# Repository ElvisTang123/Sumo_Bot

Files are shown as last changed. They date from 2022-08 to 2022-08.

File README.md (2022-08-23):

<p align="center">
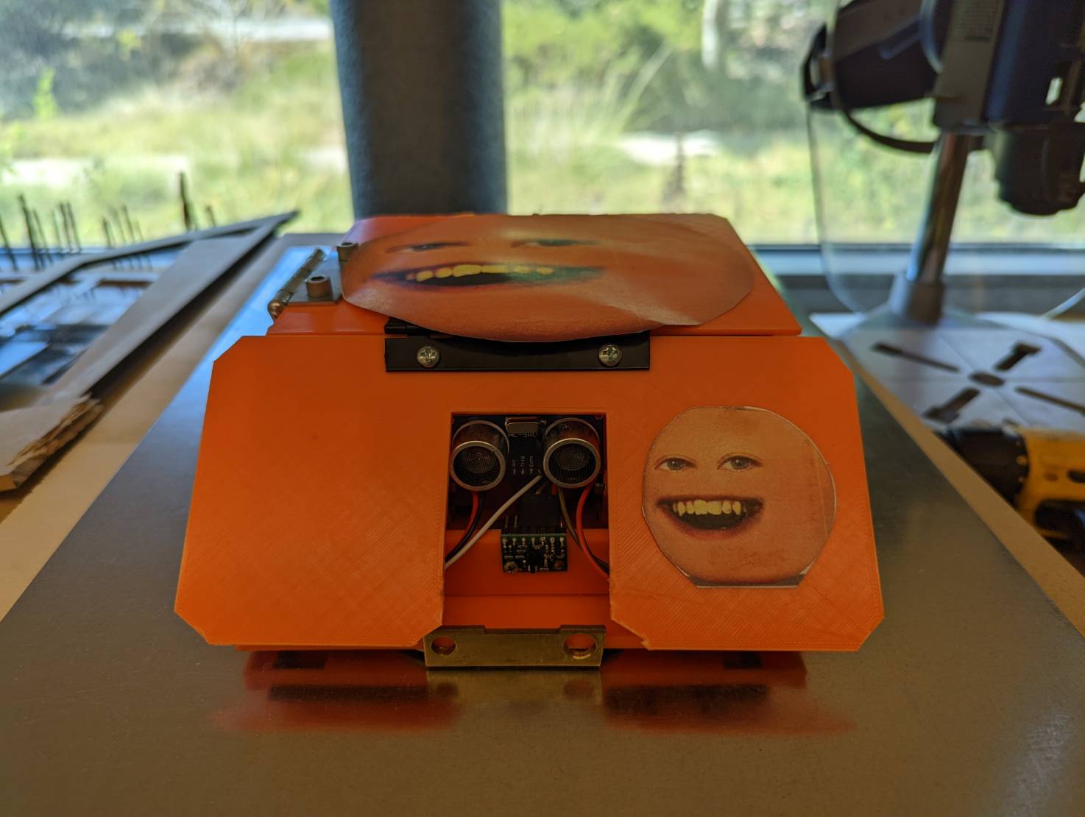
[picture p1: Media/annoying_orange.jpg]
  
</p>

<div align="center">
  <h1>Sumo_Bot - Annoying Orange</h1>
</div>

# Project Introduction
Sumo Bot is a sport that two robots try to push each other out of the circle arena. In order to push other robot out and keep themselves in the arena, normally there are a few line detect sensors at the bottom of the robot to sense the edge of the arena and couples of distance sensors on the robot to measure their opponents' location.<br />
In this project, we are going to build a sumo bot from scratch. This includes the PCB design, car shell CAD design, and firmware development for motors, sensors and other electronic components.<br />

# Table of Contents
* [Accomplishments](#accomplishments)
* [Bill of Materials](#bill-of-materials)
* [Mechanical Design](#mechanical-design)
* [PCB Design](#pcb-design)
* [High Level Wiring Diagram](#high-level-wiring-diagram)
* [Demonstration](#demonstration)

# Accomplishments
* Built a robot with 4 DC motors, 2 light reflect sensors, a laser ToF sensor, an IMU sensor, and a 3D printed shell
* Designed a PCB board containing voltage regulator, fuse, MCU chip, motor drivers, and voltage monitoring circuit
* Developed mannul mode (control the robot with remote control) and auto mode (robot's action is based on sensors' data feedback) for sumo bot control
* Designed the auto mode algorithms according to the sensors' data feedback in C programming

# Bill of Materials

| Components | Part # | Quantity |
| :---:  | :---: |:---: |
| DC Motor | 25D HP 12V Metal Gearmotors| 4 |
| Motor Driver |DRV8800PWP|4|
| ToF Laser Sensor | VL53L0X |1|
| Ultrasonic Distance Sensor | HC-SR04 |1|
| Infrared Reflective Sensor | TCRT5000 |2|
| Inertial measurement unit | MPU6050 |1|
| Remote Control Receiver | DUMBORC X6F |1|
| Wheels | JS4311 Aluminum |3|
| PCB Board | --- |1|

# Mechanical Design
The full CAD model for the assembly of the sumo bot can be found in the [CAD folder](https://github.com/ElvisTang123/Sumo_Bot/tree/main/CAD%20Files)
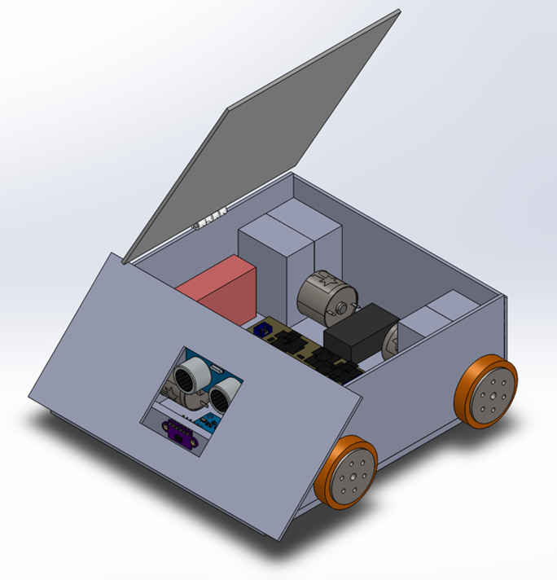
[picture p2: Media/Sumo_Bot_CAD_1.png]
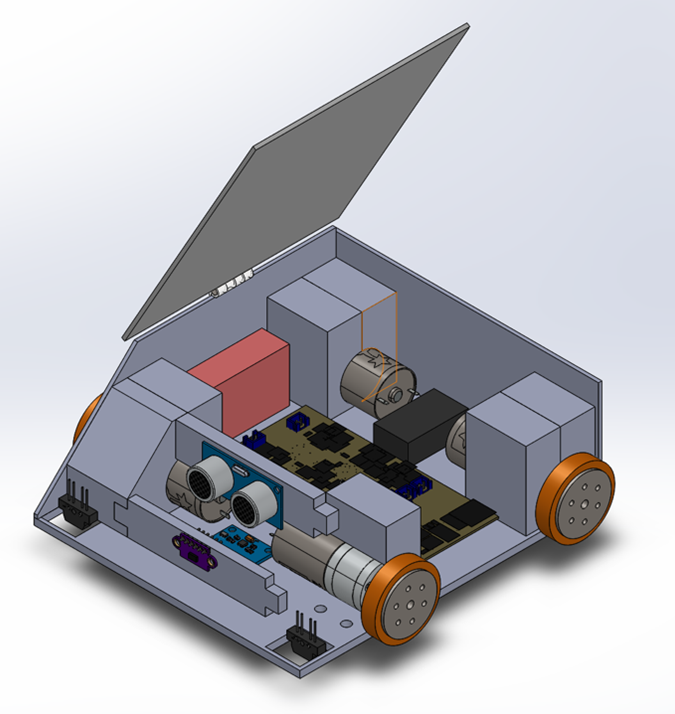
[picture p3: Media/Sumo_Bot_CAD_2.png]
|  | |
| --- | --- |

# PCB Design
The schematic and layout of the PCB board can be found in the [PCB Design](https://github.com/ElvisTang123/Sumo_Bot/tree/main/PCB%20Design)
<p align="center">
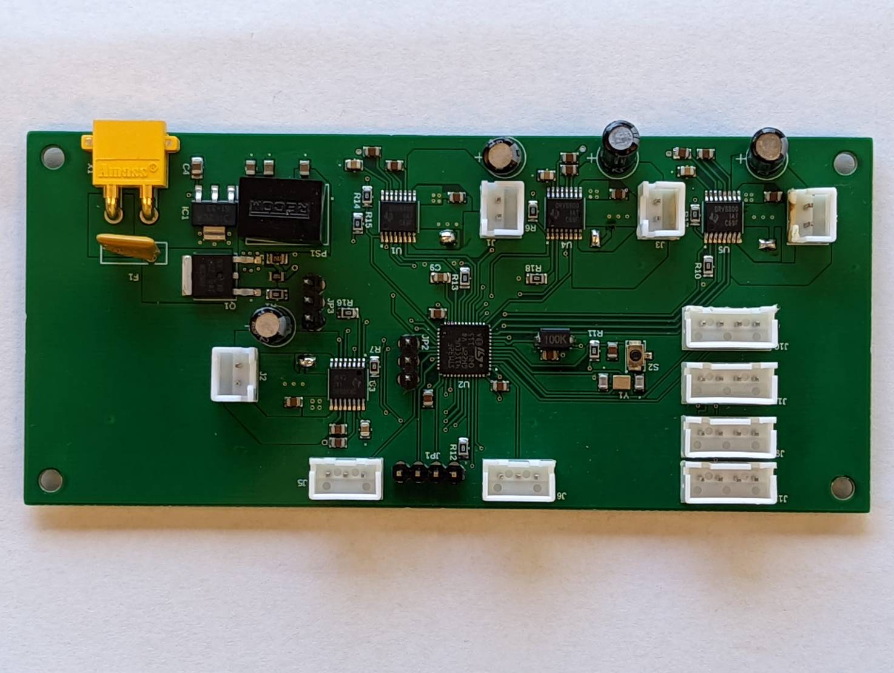
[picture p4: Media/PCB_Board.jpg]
  
</p>

# High Level Wiring Diagram
<p align="center">
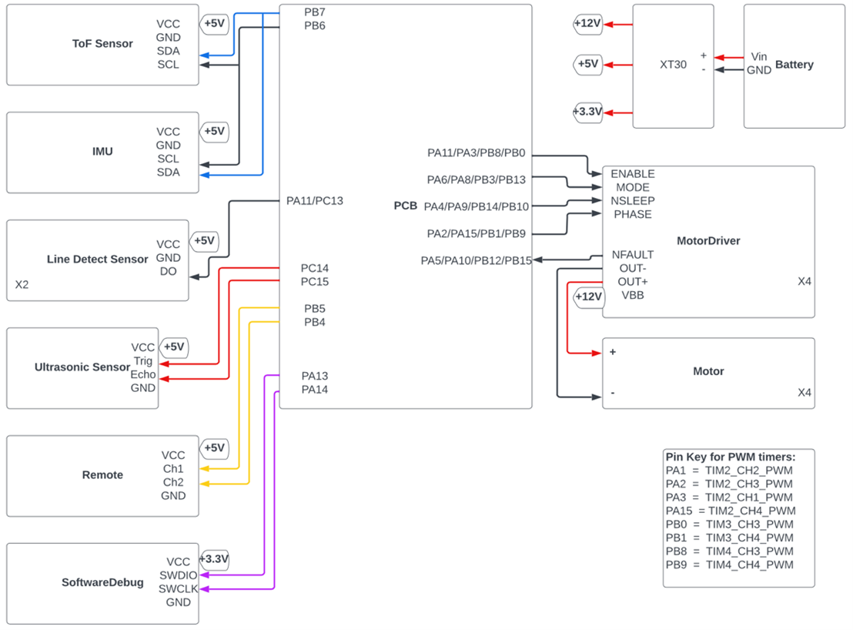
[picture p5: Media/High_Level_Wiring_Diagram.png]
  
</p>

# Demonstration
Demo (https://www.youtube.com/watch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)

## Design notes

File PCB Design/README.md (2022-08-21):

# PCB Design

# Schematic
<p align="center">
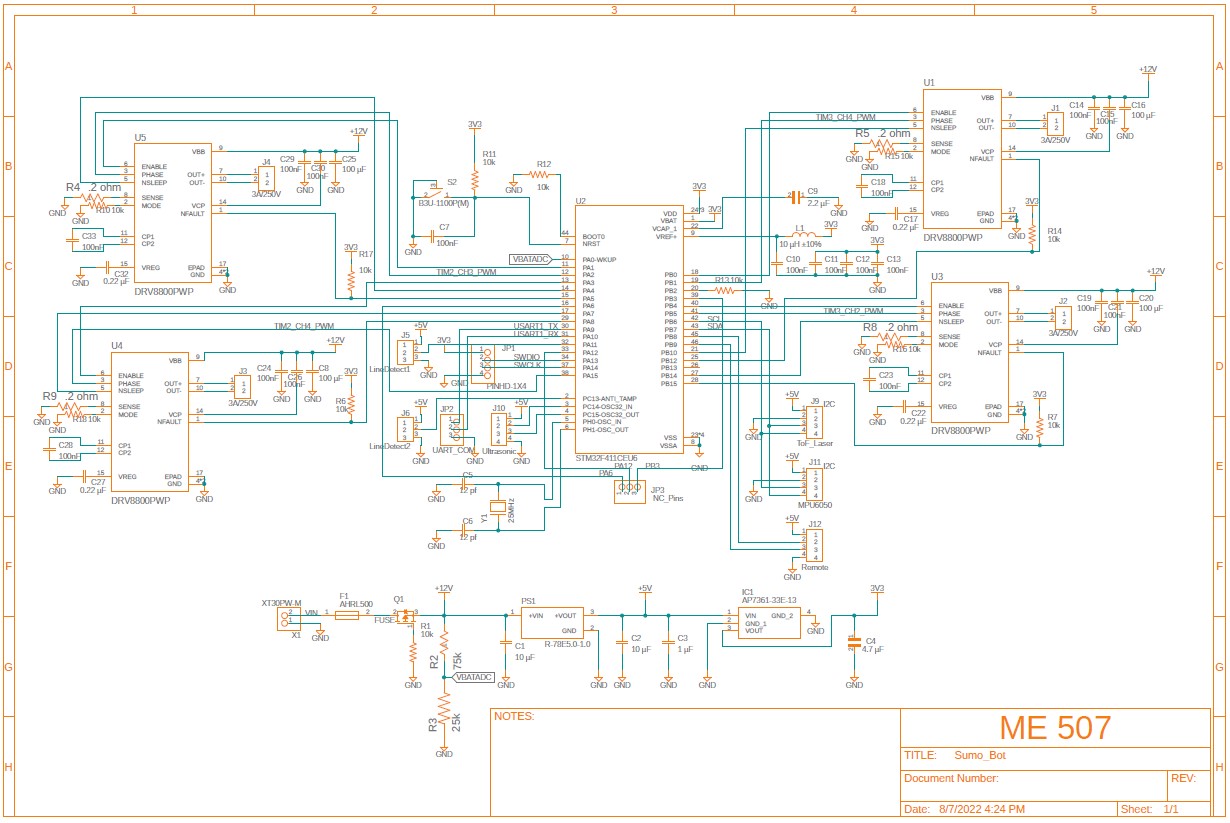
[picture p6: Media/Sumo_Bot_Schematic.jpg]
  
</p>

# PCB Layout
<p align="center">
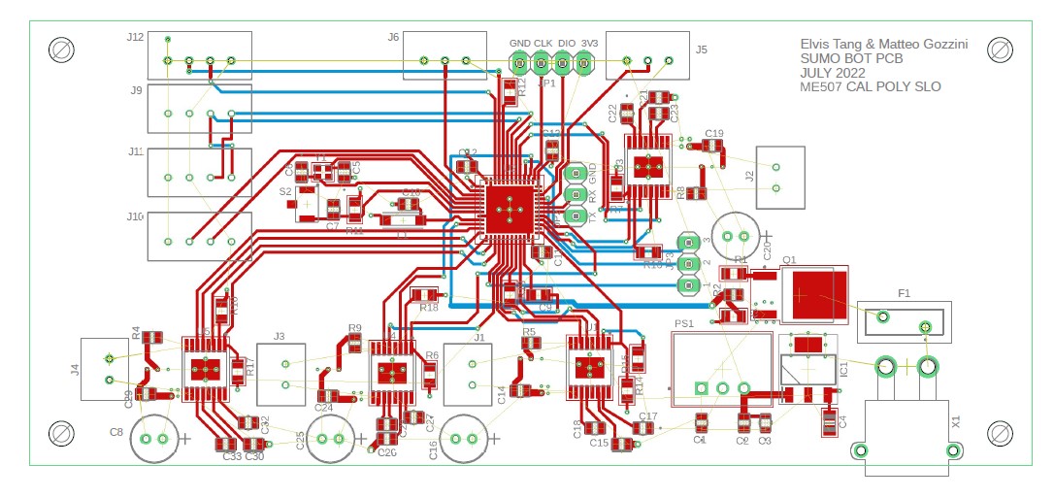
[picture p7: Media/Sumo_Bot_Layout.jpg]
  
</p>

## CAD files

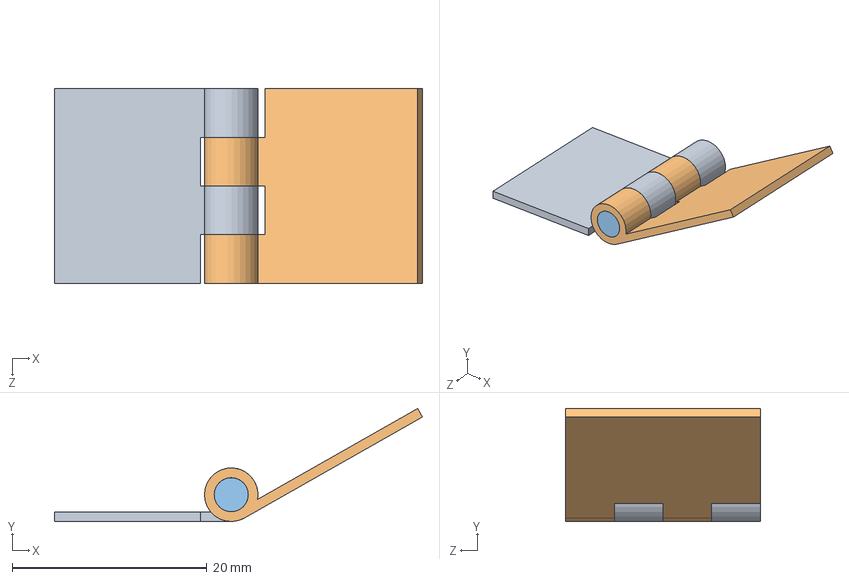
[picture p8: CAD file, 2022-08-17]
CAD Files/HingeAssembly.SLDASM
37.8 x 11.6 x 20.0 mm
hinge1
Hinge2
Hinge Rod

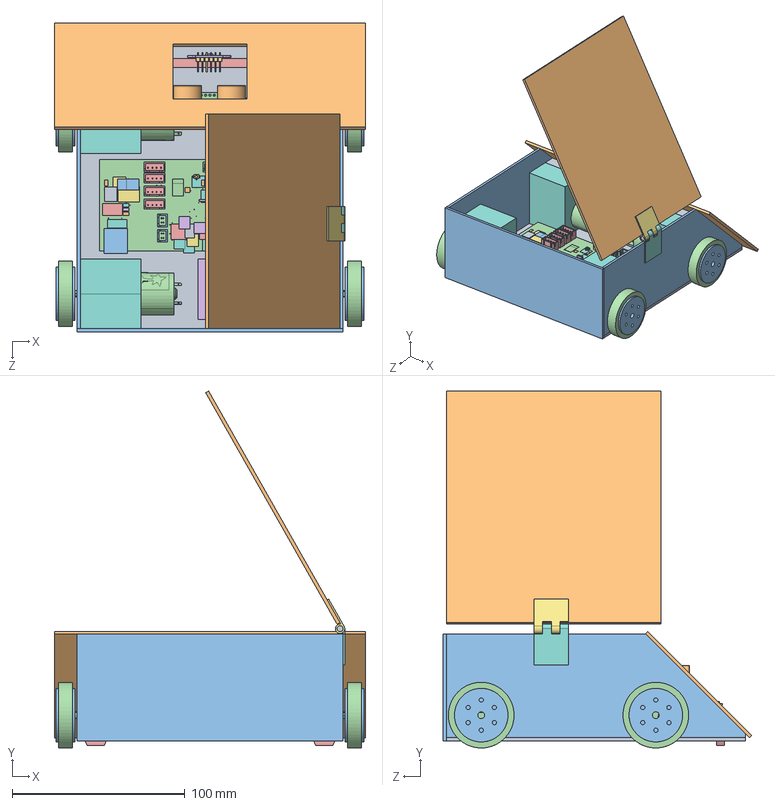
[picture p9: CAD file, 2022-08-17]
CAD Files/Assem1.SLDASM
180.0 x 206.5 x 178.5 mm
bottomPlate
AngleWall
SideWall x 2
25d-metal-gearmotor-34-47 x 4
HOA0149-001 x 2
vl53l0x_PCB
pin_header x 6
motHolder x 6
angledMotHolder
HC-SR04 Ultrasonic sensor
steelwheel x 4
rubberwheel x 4
battery
reciever
hinge1
Hinge2
Hinge Rod
topplate
backplate
PCB, MPU-9255
SMD Resistor, 10kΩ, MPU-9255 x 5
SMD Capacitor, MPU-9255 x 5
MPU-9255 IC
MIC5205 Low Noise LDO, MPU-9255
Tantalum Capacitor, 15uF, MPU-9255
B3U1100P(M)_3dmodel_1602235044.step
B2B-XH-A v1.step x 4
B3B-XH-A v1.step x 2
B4B-XH-A v1.step x 4
RESC2012X65N.step
CAP_CL21_SAM-L.step
AHRL500AP.step
SOT230P700X180-4N.step
CAPC2012X140N.step
CAPC2012X135N.step
1X04.step
TO229P990X239-3N.step
INDC4509X190.step
CONV_R-78E5.0-1.0.step
RESC2012X60N.step
QFN50P700X700X60-49N.step
XTAL_SXT2149BA38-25.000MT.step
CAP_CL_21_SAM-L.step x 2
CAP_CC0805_YAG-L.step x 2
CAP_YX_5X11_RUB.step x 4
73L3R20J_CTS-L.step x 4
CAP_885012207_WRE-L.step x 4
YAG_CC0805_YAG-L.step x 17
SOP65P640X120-17N.step x 4
RESC2012X70N.step x 8
XT30PW-M.step
Board.step
bot-angle
top-angle

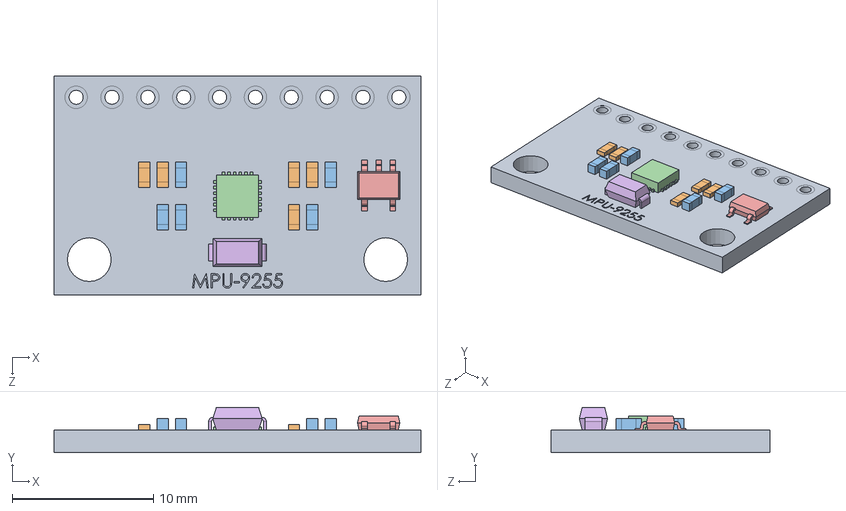
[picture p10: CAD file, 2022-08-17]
CAD Files/MPU-9255.SLDASM
26.0 x 3.20 x 15.5 mm
PCB, MPU-9255
SMD Resistor, 10kΩ, MPU-9255 x 5
SMD Capacitor, MPU-9255 x 5
MPU-9255 IC
MIC5205 Low Noise LDO, MPU-9255
Tantalum Capacitor, 15uF, MPU-9255

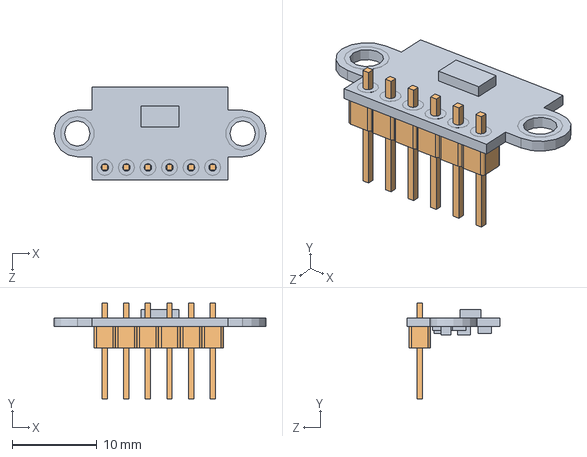
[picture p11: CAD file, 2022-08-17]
CAD Files/vl53l0x.SLDASM
25.0 x 11.3 x 11.0 mm
vl53l0x_PCB
pin_header x 6

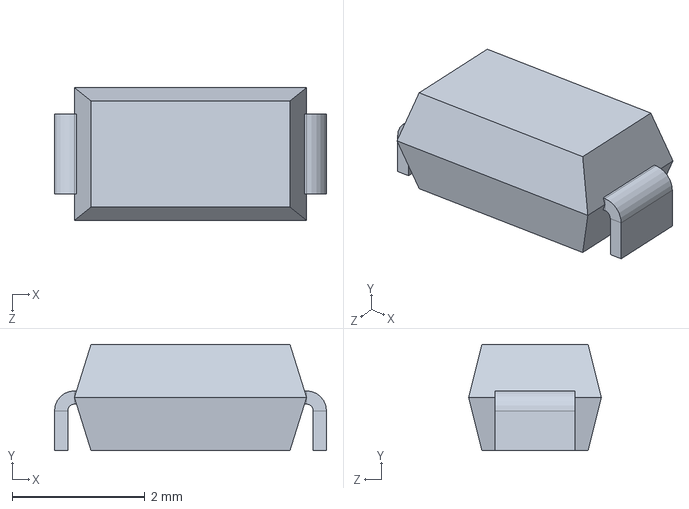
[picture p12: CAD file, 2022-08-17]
CAD Files/Tantalum Capacitor, 15uF, MPU-9255.SLDPRT
4.10 x 1.60 x 2.00 mm

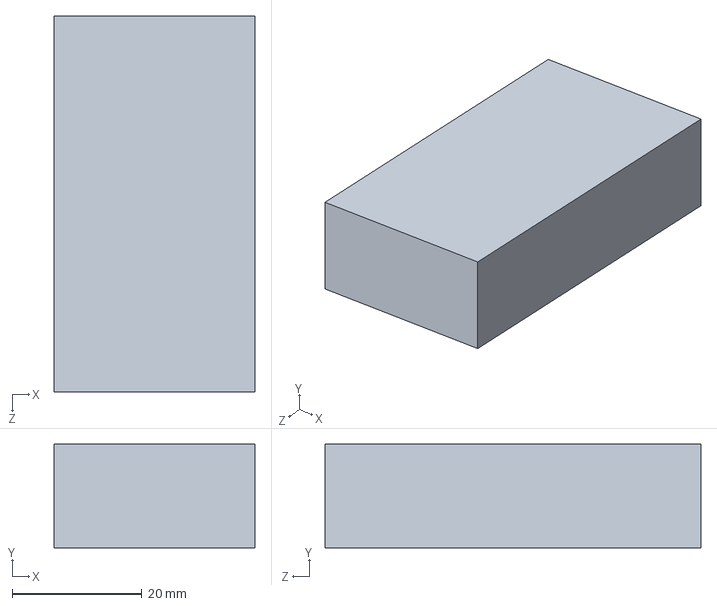
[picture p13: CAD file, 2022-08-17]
CAD Files/battery.SLDPRT
31.0 x 16.0 x 58.0 mm

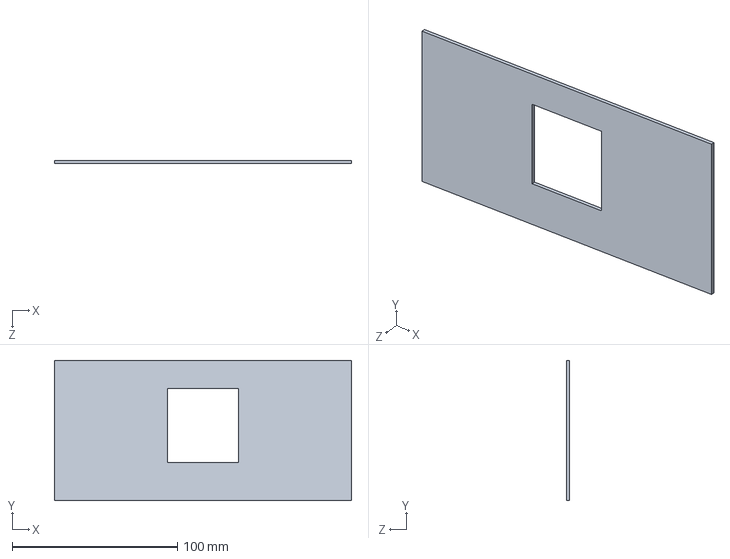
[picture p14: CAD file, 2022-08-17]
CAD Files/AngleWall.SLDPRT
180.0 x 85.0 x 2.00 mm

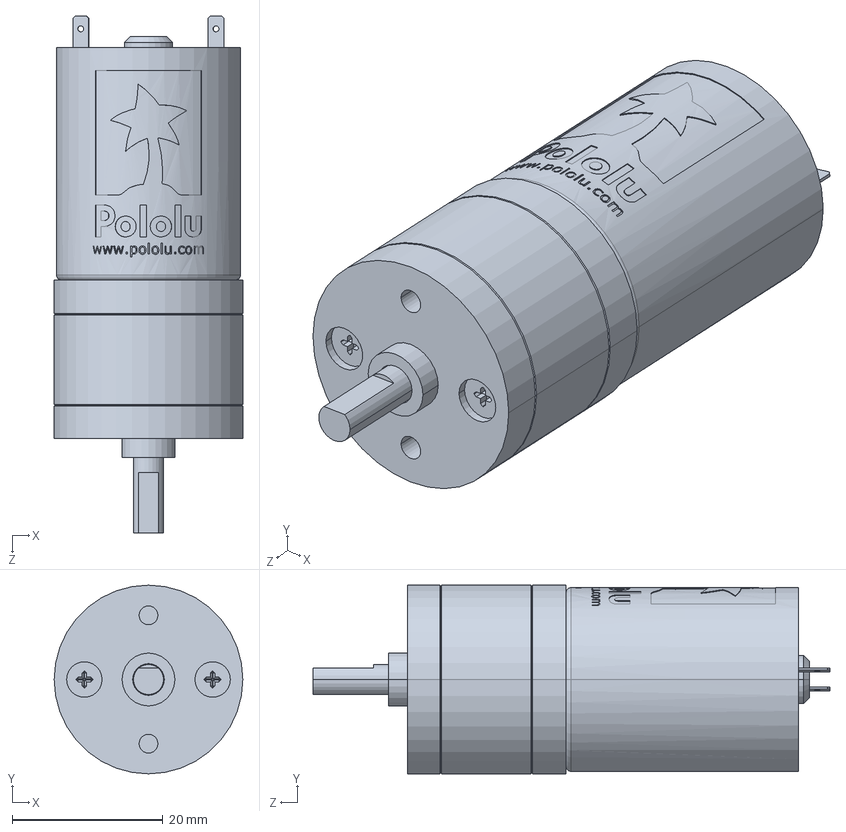
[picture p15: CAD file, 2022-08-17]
CAD Files/25d-metal-gearmotor-34-47.SLDPRT
25.0 x 25.0 x 68.5 mm

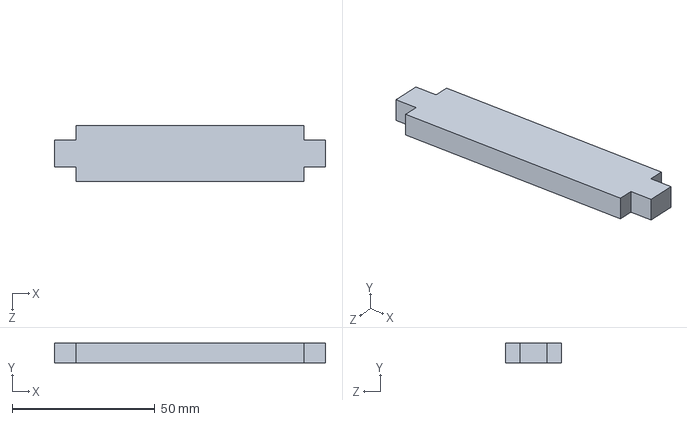
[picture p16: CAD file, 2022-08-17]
CAD Files/top-angle.SLDPRT
95.0 x 7.00 x 19.5 mm

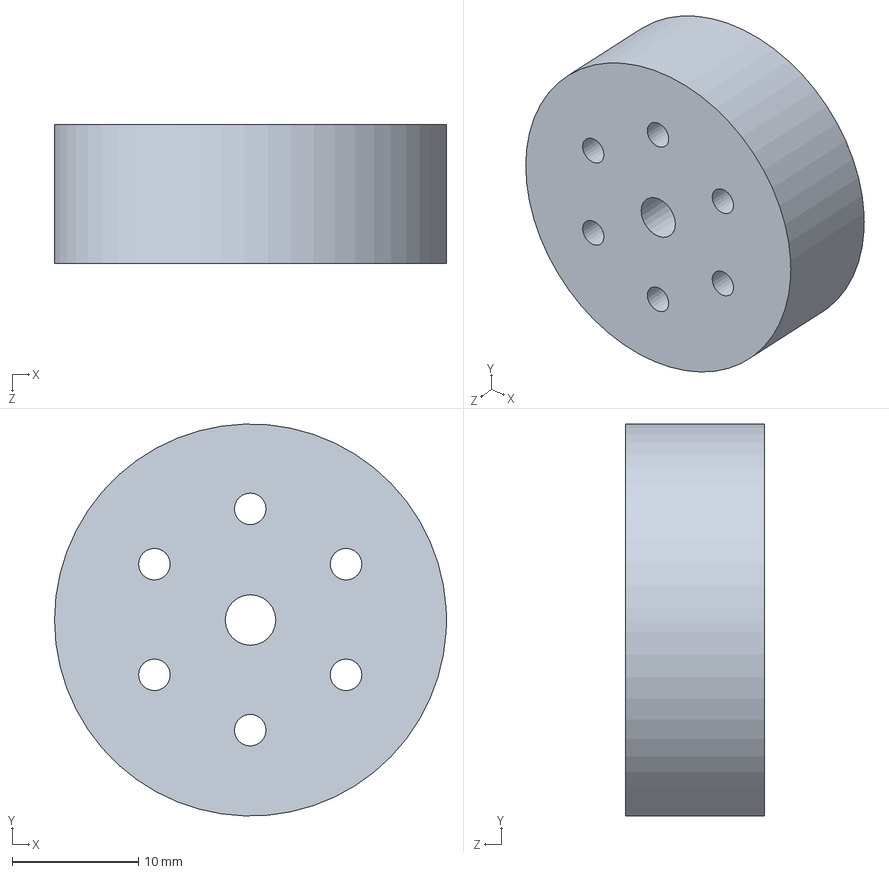
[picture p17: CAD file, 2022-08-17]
CAD Files/steelwheel.SLDPRT
31.0 x 31.0 x 11.0 mm

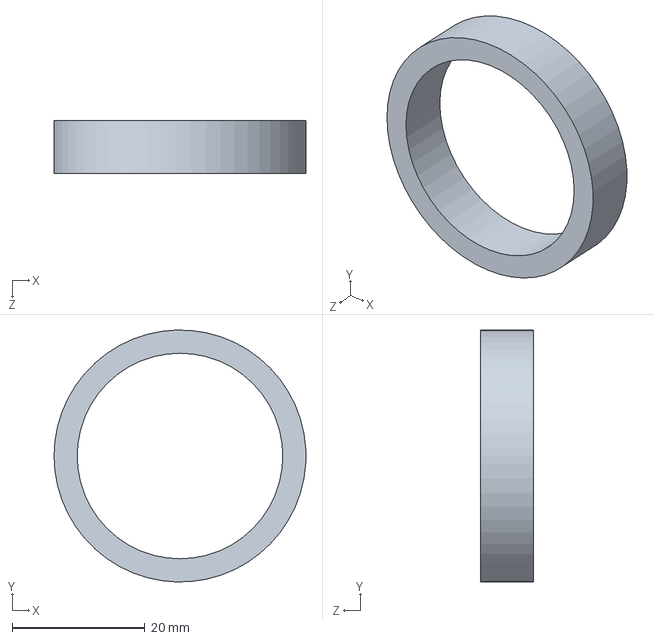
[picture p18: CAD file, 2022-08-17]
CAD Files/rubberwheel.SLDPRT
38.0 x 38.0 x 8.00 mm

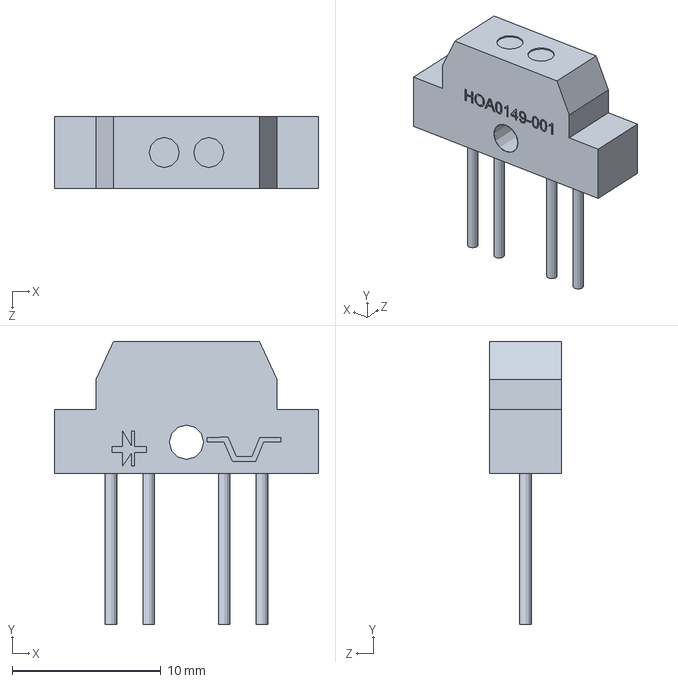
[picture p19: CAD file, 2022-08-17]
CAD Files/HOA0149-001.SLDPRT
17.8 x 19.1 x 4.83 mm

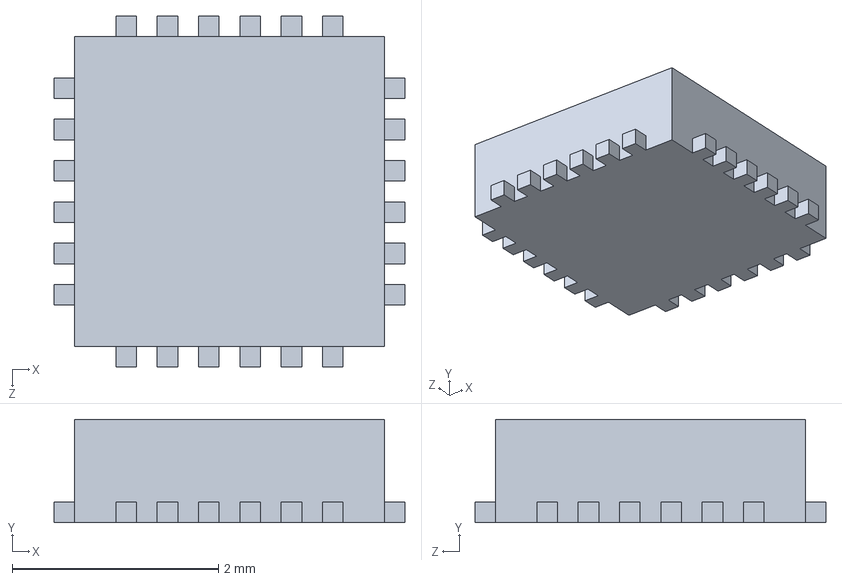
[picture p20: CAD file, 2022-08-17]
CAD Files/MPU-9255 IC.SLDPRT
3.40 x 1.00 x 3.40 mm

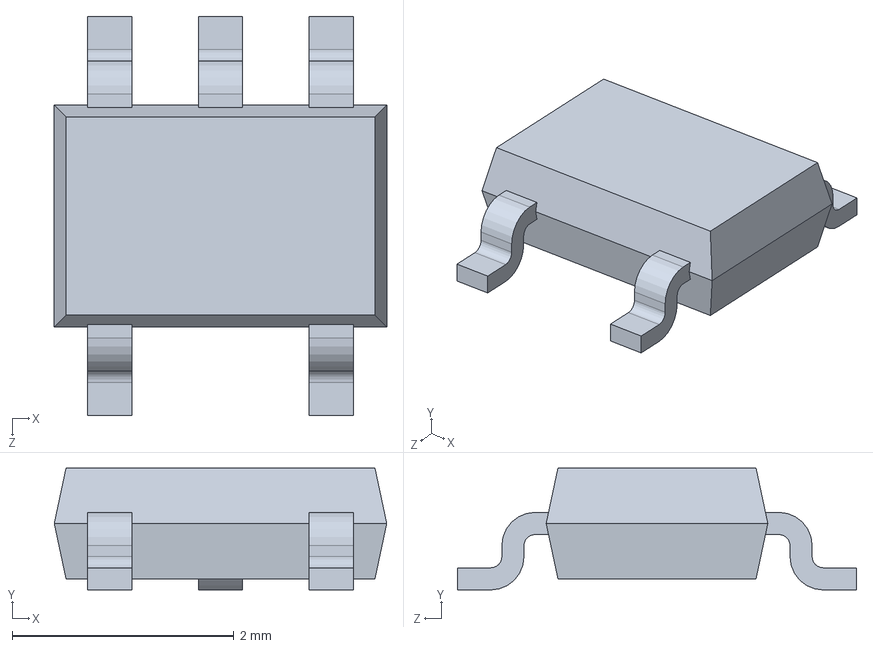
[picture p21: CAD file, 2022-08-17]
CAD Files/MIC5205 Low Noise LDO, MPU-9255.SLDPRT
3.00 x 1.10 x 3.60 mm

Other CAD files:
CAD Files/angledMotHolder.SLDPRT
CAD Files/topplate.SLDPRT
CAD Files/Hinge Rod.SLDPRT
CAD Files/SMD Capacitor, MPU-9255.SLDPRT
CAD Files/HC-SR04 Ultrasonic sensor.SLDPRT
CAD Files/Hinge2.SLDPRT
CAD Files/PCB, MPU-9255.SLDPRT
CAD Files/SMD Resistor, 10kΩ, MPU-9255.SLDPRT
CAD Files/SideWall.SLDPRT
CAD Files/backplate.SLDPRT
CAD Files/bot-angle.SLDPRT
CAD Files/bottomPlate.SLDPRT
CAD Files/hinge1.SLDPRT
CAD Files/motHolder.SLDPRT
CAD Files/pin_header.SLDPRT
CAD Files/reciever.SLDPRT
CAD Files/vl53l0x_PCB.SLDPRT
PCB Design/Sumo_Bot_PCB.f3z

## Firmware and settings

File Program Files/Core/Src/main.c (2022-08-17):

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
/* Includes ------------------------------------------------------------------*/
#include "main.h"

/* USER CODE BEGIN Includes */
#include <string.h>
#include <stdio.h>
#include "vl53l0x_api.h"
//#include "vl53l0x_platform.h"

#include "MPU6050.h"
#include "Line_Detect.h"
#include "USART.h"
#include "HCSR04.h"
#include "motor_driver.h"
#include "Remote_Control.h"
#include "lidar.h"

/* USER CODE END Includes */

/* USER CODE BEGIN PD */
#define LIDAR_ADDR (0b0101001 << 1)
#define LIDAR_REF1 (0xC0)
#define LIDAR_REF2 (0xC1)
#define LIDAR_REF3 (0xC2)
#define LIDAR_REF4 (0x51)
#define LIDAR_REF5 (0x61)
/* USER CODE END PD */

ADC_HandleTypeDef hadc1;

I2C_HandleTypeDef hi2c1;

TIM_HandleTypeDef htim1;
TIM_HandleTypeDef htim2;
TIM_HandleTypeDef htim3;
TIM_HandleTypeDef htim4;

UART_HandleTypeDef huart1;

/* USER CODE BEGIN PV */

MPU6050 IMU_1;
IR_Sensor IR1;
IR_Sensor IR2;
HCSR04 US;
Motor_t  motor_1;
Motor_t  motor_3;
RC_t throttle;
RC_t steering;
uint16_t duty;
uint16_t ADCValue;
VL53L0X_Dev_t lidar1_dev;
VL53L0X_DEV lidar1 = &lidar1_dev;

int8_t state = 0;
int16_t Auto_CNT = 0;
int16_t Auto_Target = 5;
int16_t Man_CNT = 0;
int16_t Man_Target = 5;
uint16_t LongDistTarget = 90;
uint16_t ShortDistTarget = 50;
uint32_t timeout;
uint8_t setLevel = 5;
/* USER CODE END PV */

void SystemClock_Config(void);
static void MX_GPIO_Init(void);
static void MX_ADC1_Init(void);
static void MX_I2C1_Init(void);
static void MX_TIM2_Init(void);
static void MX_TIM3_Init(void);
static void MX_TIM4_Init(void);
static void MX_USART1_UART_Init(void);
static void MX_TIM1_Init(void);
/* USER CODE BEGIN 0 */
void delay_us (uint16_t us)
{
	__HAL_TIM_SET_COUNTER(&htim1,0);  // set the counter value a 0
	while (__HAL_TIM_GET_COUNTER(&htim1) < us);  // wait for the counter to reach the us input in the parameter
}
/* USER CODE END 0 */

/**
 * @brief  The application entry point.
 * @retval int
 */
int main(void)
{
	/* USER CODE BEGIN 1 */

	// MPU6050 struct attribute config
	IMU_1.hi2c = &hi2c1;
	IMU_1.Accel_X = 0;
	IMU_1.Accel_Y = 0;
	IMU_1.Accel_Z = 0;
	IMU_1.Gyro_X = 0;
	IMU_1.Gyro_Y = 0;
	IMU_1.Gyro_Z = 0;

	// IR Sensor struct attribute config
	IR1.DI_GPIO = GPIOA;
	IR1.IDR_Mask = GPIO_IDR_ID11;
	IR1.IDR_Pos = GPIO_IDR_ID11_Pos;

	IR2.DI_GPIO = GPIOC;
	IR2.IDR_Mask = GPIO_IDR_ID13;
	IR2.IDR_Pos = GPIO_IDR_ID13_Pos;

	// HCSR04 struct attribute config
	US.Trig_GPIO = GPIOC;
	US.Trig_Pin = GPIO_PIN_14;
	US.Echo_GPIO = GPIOC;
	US.Echo_IDR_Mask = GPIO_IDR_ID15;
	US.Echo_IDR_Pos = GPIO_IDR_ID15_Pos;

	// Motor struct attribute config
	motor_1.htim = &htim2;
	motor_1.IN1_GPIO = GPIOA;
	motor_1.IN1_pin = TIM_CHANNEL_2;
	motor_1.IN2_GPIO = GPIOA;
	motor_1.IN2_pin = TIM_CHANNEL_3;
	motor_1.EN_GPIO = GPIOA;
	motor_1.EN_pin = GPIO_PIN_4;

	motor_3.htim = &htim3;
	motor_3.IN1_GPIO = GPIOB;
	motor_3.IN1_pin = TIM_CHANNEL_3;
	motor_3.IN2_GPIO = GPIOB;
	motor_3.IN2_pin = TIM_CHANNEL_4;
	motor_3.EN_GPIO = GPIOB;
	motor_3.EN_pin = GPIO_PIN_10;

	// Remote Control struct attribute config
	throttle.htim = &htim4;
	throttle.TIM_CH = TIM_CHANNEL_3;
	throttle.GPIO = GPIOB;
	throttle.IDR_Mask = GPIO_IDR_ID8;
	throttle.IDR_Pos = GPIO_IDR_ID8_Pos;


	steering.htim = &htim4;
	steering.TIM_CH = TIM_CHANNEL_4;
	steering.GPIO = GPIOB;
	steering.IDR_Mask = GPIO_IDR_ID9;
	steering.IDR_Pos = GPIO_IDR_ID9_Pos;

	// ToF Sensor variables
	uint8_t mdr1;
	VL53L0X_RangingMeasurementData_t range_data1;
	uint16_t tof_data;
	/* USER CODE END 1 */

	/* MCU Configuration--------------------------------------------------------*/

	/* Reset of all peripherals, Initializes the Flash interface and the Systick. */
	HAL_Init();

	/* Configure the system clock */
	SystemClock_Config();

	/* Initialize all configured peripherals */
	MX_GPIO_Init();
	MX_ADC1_Init();
	MX_I2C1_Init();
	MX_TIM2_Init();
	MX_TIM3_Init();
	MX_TIM4_Init();
	MX_USART1_UART_Init();
	MX_TIM1_Init();
	/* USER CODE BEGIN 2 */

	HAL_ADC_Start(&hadc1);

	MPU6050_Init(&IMU_1);

	HAL_TIM_Base_Start(&htim1);		// Start TIM1 for delay function
	HAL_TIM_Base_Start(&htim4);		// Start TIM4 for external interrupt (PC15) counter reading

	HAL_TIM_IC_Start_IT(&htim4, TIM_CHANNEL_3);	// Capturing RC throttle PWM with TIM4
	HAL_TIM_IC_Start_IT(&htim4, TIM_CHANNEL_4);	// Capturing RC steering PWM with TIM4

	HAL_TIM_PWM_Start(&htim2, TIM_CHANNEL_2);	// PWM signals to motor 1
	HAL_TIM_PWM_Start(&htim2, TIM_CHANNEL_3);	// PWM signals to motor 1
	HAL_TIM_PWM_Start(&htim3, TIM_CHANNEL_3);	// PWM signals to motor 3
	HAL_TIM_PWM_Start(&htim3, TIM_CHANNEL_4);	// PWM signals to motor 3

	// Set both nSleep Pin and Enable Pin high to enable the motor driver
	enable(&motor_1);
	enable(&motor_3);

	// ToF
	init_lidar(lidar1, &hi2c1); 				// Initialize the device with the i2c handle it is connected to
	check_ref_reg(lidar1, &huart1);				// Check the reference registers, to verify that i2c communication is working
	VL53L0X_Error Status = VL53L0X_ERROR_NONE;	// Initialize the sensor, I reccomend starting to check for errors at this point
	if (Status == VL53L0X_ERROR_NONE)
		Status = setup_lidar_continuous(lidar1);

	/* USER CODE END 2 */

	/* Infinite loop */
	/* USER CODE BEGIN WHILE */
	while (1)
	{


		// MPU6050
		// Acceleration
		//		HAL_Delay(1000);
		//		UART_Print_String("-------------------------------------\r\n");
		//		UART_Print_String("MPU6050\r\n");
		//		UART_Print_String("Acceleration\r\n");
		//MPU6050_Read_Accel(&IMU_1);
		//		UART_MPU6050_ACC(IMU_1.Ax,'x');
		//		UART_MPU6050_ACC(IMU_1.Ay,'y');
		//		UART_MPU6050_ACC(IMU_1.Az,'z');
		//		UART_Print_String("\r\n");
		// Angular Velocity
		//		UART_Print_String("Angular Velocity\r\n");
		//MPU6050_Read_Gyro(&IMU_1);
		//		UART_MPU6050_Gyro(IMU_1.Gx,'x');
		//		UART_MPU6050_Gyro(IMU_1.Gy,'y');
		//		UART_MPU6050_Gyro(IMU_1.Gz,'z');
		//		UART_Print_String("-------------------------------------\r\n");

		// Finite State Machine
		switch(state){
		case 0:									// mode select state
			if(steering.usWidth > 1800){
				Auto_CNT++;
				Man_CNT = 0;
				if(Auto_CNT == Auto_Target){
					Auto_CNT = 0;
					state = 5;
				}
				else{
					state = 0;
				}

			}
			else if(steering.usWidth < 1200){
				Man_CNT++;
				Auto_CNT = 0;
				if(Man_CNT == Man_Target){
					Man_CNT = 0;
					state = 4;
				}
				else{
					state = 0;
				}
			}
			else{
				Auto_CNT = 0;
				Man_CNT = 0;
				state = 0;
			}
			break;
		case 1:									//	attack state
			while(throttle.usWidth < 1850){
				set_level(&motor_1, 0);
				set_level(&motor_3, 0);
			}
			// Sensor Read
			// HC-SRO4
			HAL_GPIO_WritePin(US.Trig_GPIO, US.Trig_Pin, GPIO_PIN_SET);  // pull the TRIG pin HIGH
			delay_us (10);  // wait for 10 us
			HAL_GPIO_WritePin(US.Trig_GPIO, US.Trig_Pin, GPIO_PIN_RESET);

			// VL53L0X_ToF Sensor
			if (Status == VL53L0X_ERROR_NONE)
				Status = VL53L0X_GetMeasurementDataReady(lidar1, &mdr1);
			if (mdr1 && Status == VL53L0X_ERROR_NONE)
			{
				Status = VL53L0X_GetRangingMeasurementData(lidar1, &range_data1);
				tof_data = (range_data1.RangeMilliMeter)/10; //converted to cm for simplicity
				UART_Print_Val("Range (cm): %d cm\r\n" , tof_data);
				VL53L0X_ClearInterruptMask(lidar1, VL53L0X_REG_SYSTEM_INTERRUPT_GPIO_NEW_SAMPLE_READY);
			}

			// Strategy Starts From Here

			UART_Print_Val("US Stuff (cm): %d\r\n cm", US.EXTI_Diff);



			if ((tof_data < ShortDistTarget) || (US.EXTI_Diff < ShortDistTarget)){
				set_level(&motor_1, -2048);
				set_level(&motor_3, 2048);
			}

			else {

				set_level(&motor_1, -2048);
				set_level(&motor_3, -2048);
			}

			state = 2;
			break;

		case 2:									//	Line Detect State
			// Line Detect
			//UART_Print_String("Line Detect 1\r\n");
			LineDetect(&IR1);
			//UART_Print_String("Line Detect 2\r\n");
			LineDetect(&IR2);
			//		UART_Print_String("-------------------------------------\r\n");
			//			set_level(&motor_1, 0);
			//			set_level(&motor_3, 0);
			// Strategy Starts From Here

			if ((IR2.DI_GPIO->IDR & IR2.IDR_Mask) <100){
				//uint32_t start = HAL_GetTick();
				//timeout = HAL_GetTick() + setLevel;
				//UART_Print_Val("time %d \r\n", HAL_GetTick());
				set_level(&motor_1, 2048);
				set_level(&motor_3, -2048);
				HAL_Delay(70);
				set_level(&motor_1, -2048);
				set_level(&motor_3, -2048);
				HAL_Delay(350);


			}

			else if ((IR1.DI_GPIO->IDR & IR1.IDR_Mask)<100){
				set_level(&motor_1, 2048);
				set_level(&motor_3, -2048);
				HAL_Delay(70);
				set_level(&motor_1, 2048);
				set_level(&motor_3, 2048);
				HAL_Delay(350);
			}


			//UART_Print_Val("color %d \r\n", IR1.DI_GPIO->IDR & IR1.IDR_Mask);
			//UART_Print_Val("color %d \r\n", IR2.DI_GPIO->IDR & IR2.IDR_Mask);
			//UART_Print_Val("color %d \r\n", IR1.IDR_Mask);
			//			if(){
			//
			//			}

			state = 3;
			break;
		case 3:
			//Battery Monitoring
			HAL_ADC_Start(&hadc1);
			HAL_ADC_PollForConversion(&hadc1,1000);
			ADCValue = HAL_ADC_GetValue(&hadc1);
			//UART_Print_Val("ADC Value: %d\r\n", ADCValue);

			HAL_ADC_Stop(&hadc1);
			if (ADCValue < 2880)
			{
				disable(&motor_1);
				disable(&motor_3);
				state = 3;
			}
			else if (ADCValue >= 2880)
			{
				enable(&motor_1);
				enable(&motor_3);
				state = 1;
			}
			break;
		case 4:									// Manual Mode

			UART_Print_Val("Throttle: %d\r\n", throttle.usWidth);
			UART_Print_Val("Steering: %d\r\n", steering.usWidth);

			if(throttle.usWidth > 2000){
				throttle.usWidth = 2000;
			}
			else if(throttle.usWidth < 1000){
				throttle.usWidth = 1000;
			}
			if(steering.usWidth > 2000){
				steering.usWidth = 2000;
			}
			else if(steering.usWidth < 1000){
				steering.usWidth = 1000;
			}

			if (throttle.usWidth>1550){
				duty = (-2048/500)*(throttle.usWidth -1500);
				set_level(&motor_1, -duty);
				set_level(&motor_3, +duty);
			}
			else if(throttle.usWidth<1450){
				duty = (2048/500)*(1500-throttle.usWidth);
				set_level(&motor_1, duty);
				set_level(&motor_3, -duty);
			}
			else if(throttle.usWidth>1450 && throttle.usWidth<1550){
				duty = 0;
				set_level(&motor_1, duty);
				set_level(&motor_3, duty);
			}

			if (steering.usWidth>1550 && throttle.usWidth >1550){
				duty = (2048/500)*(throttle.usWidth-1500);
				set_level(&motor_1, -duty);
				set_level(&motor_3, -duty);
			}
			else if  (steering.usWidth>1550 && throttle.usWidth < 1450){
				duty = (2048/500)*(1500-throttle.usWidth);
				set_level(&motor_1, -duty);
				set_level(&motor_3, -duty);
			}

			else if (steering.usWidth <1450 && throttle.usWidth >1550){
				duty = (2048/500)*(throttle.usWidth-1500);
				set_level(&motor_1, +duty);
				set_level(&motor_3, +duty);
			}
			else if  (steering.usWidth <1450 && throttle.usWidth < 1450){
				duty = (2048/500)*(1500-throttle.usWidth);
				set_level(&motor_1, +duty);
				set_level(&motor_3, +duty);
			}

			break;
		case 5:
			while(throttle.usWidth < 1850){
				set_level(&motor_1, 0);
				set_level(&motor_3, 0);
			}
			set_level(&motor_1, 2048);
			set_level(&motor_3, 2048);
			HAL_Delay(220);
			set_level(&motor_1, 2048);
			set_level(&motor_3, -2048);
			HAL_Delay(300);
			state = 1;
		default:
			UART_Print_String("BAD CODE LOLOLOL\r\n");
		}




		//		HAL_Delay(1000);

		/* USER CODE END WHILE */

		/* USER CODE BEGIN 3 */
	}
	/* USER CODE END 3 */
}

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
/* USER CODE BEGIN 4 */

void HAL_TIM_IC_CaptureCallback(TIM_HandleTypeDef *htim){

	// Throttle
	if(throttle.GPIO->IDR & throttle.IDR_Mask){ //throttle.Edge_Flag == 0
		throttle.IC_Val1 = HAL_TIM_ReadCapturedValue(throttle.htim, throttle.TIM_CH); // read the first value
	}
	else{
		throttle.IC_Val2 = HAL_TIM_ReadCapturedValue(throttle.htim, throttle.TIM_CH);
		getWidth(&throttle);
	}


	// Steering
	if(steering.GPIO->IDR & steering.IDR_Mask){  //steering.Edge_Flag == 0
		steering.IC_Val1 = HAL_TIM_ReadCapturedValue(steering.htim, steering.TIM_CH); // read the first value
	}
	else{
		steering.IC_Val2 = HAL_TIM_ReadCapturedValue(steering.htim, steering.TIM_CH);
		getWidth(&steering);
	}

}

void HAL_GPIO_EXTI_Callback(uint16_t GPIO_Pin){

	if((US.Echo_GPIO->IDR & GPIO_IDR_ID15)){
		US.EXTI_Val1 = TIM4->CNT;
	}
	else{
		US.EXTI_Val2 = TIM4->CNT;
		HCSR04_DistCalc(&US);
	}
}

/* USER CODE END 4 */
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


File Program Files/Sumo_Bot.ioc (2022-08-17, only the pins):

Mcu.UserName=STM32F411CEUx
PA0-WKUP.Signal=ADCx_IN0
PA1.GPIO_Label=M1_IN1
PA1.Signal=S_TIM2_CH2
PA10.Signal=USART1_RX
PA11.GPIO_Label=Line_Detect1
PA11.Signal=GPIO_Input
PA13.Signal=SYS_JTMS-SWDIO
PA14.Signal=SYS_JTCK-SWCLK
PA15.GPIO_Label=M2_IN2
PA15.Signal=S_TIM2_CH1_ETR
PA2.GPIO_Label=M1_IN2
PA2.Signal=S_TIM2_CH3
PA3.GPIO_Label=M2_IN1
PA3.Signal=S_TIM2_CH4
PA4.GPIO_Label=M1_EN
PA4.Signal=GPIO_Output
PA5.GPIO_Label=M1_nFAULT
PA5.Signal=GPIO_Input
PA7.GPIO_Label=M2_EN
PA7.Signal=GPIO_Output
PA8.GPIO_Label=M2_nFAULT
PA8.Signal=GPIO_Input
PA9.Signal=USART1_TX
PB0.GPIO_Label=M3_IN1
PB0.Signal=S_TIM3_CH3
PB1.GPIO_Label=M3_IN2
PB1.Signal=S_TIM3_CH4
PB10.GPIO_Label=M3_EN
PB10.Signal=GPIO_Output
PB12.GPIO_Label=M3_nFAULT
PB12.Signal=GPIO_Input
PB14.GPIO_Label=M4_EN
PB14.Signal=GPIO_Output
PB15.GPIO_Label=M4_nFAULT
PB15.Signal=GPIO_Input
PB4.GPIO_Label=M4_IN1
PB4.Signal=S_TIM3_CH1
PB5.GPIO_Label=M4_IN2
PB5.Signal=S_TIM3_CH2
PB6.Signal=I2C1_SCL
PB7.Signal=I2C1_SDA
PB8.GPIO_Label=RC_Throttle
PB8.Signal=S_TIM4_CH3
PB9.GPIO_Label=RC_Steering
PB9.Signal=S_TIM4_CH4
PC13-ANTI_TAMP.GPIO_Label=Line_Detect2
PC13-ANTI_TAMP.Signal=GPIO_Input
PC14-OSC32_IN.Signal=GPIO_Output
PC15-OSC32_OUT.Signal=GPXTI15

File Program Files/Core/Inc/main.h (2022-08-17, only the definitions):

#define Line_Detect2_Pin GPIO_PIN_13
#define Line_Detect2_GPIO_Port GPIOC
#define M1_IN1_Pin GPIO_PIN_1
#define M1_IN1_GPIO_Port GPIOA
#define M1_IN2_Pin GPIO_PIN_2
#define M1_IN2_GPIO_Port GPIOA
#define M2_IN1_Pin GPIO_PIN_3
#define M2_IN1_GPIO_Port GPIOA
#define M1_EN_Pin GPIO_PIN_4
#define M1_EN_GPIO_Port GPIOA
#define M1_nFAULT_Pin GPIO_PIN_5
#define M1_nFAULT_GPIO_Port GPIOA
#define M2_EN_Pin GPIO_PIN_7
#define M2_EN_GPIO_Port GPIOA
#define M3_IN1_Pin GPIO_PIN_0
#define M3_IN1_GPIO_Port GPIOB
#define M3_IN2_Pin GPIO_PIN_1
#define M3_IN2_GPIO_Port GPIOB
#define M3_EN_Pin GPIO_PIN_10
#define M3_EN_GPIO_Port GPIOB
#define M3_nFAULT_Pin GPIO_PIN_12
#define M3_nFAULT_GPIO_Port GPIOB
#define M4_EN_Pin GPIO_PIN_14
#define M4_EN_GPIO_Port GPIOB
#define M4_nFAULT_Pin GPIO_PIN_15
#define M4_nFAULT_GPIO_Port GPIOB
#define M2_nFAULT_Pin GPIO_PIN_8
#define M2_nFAULT_GPIO_Port GPIOA
#define Line_Detect1_Pin GPIO_PIN_11
#define Line_Detect1_GPIO_Port GPIOA
#define M2_IN2_Pin GPIO_PIN_15
#define M2_IN2_GPIO_Port GPIOA
#define M4_IN1_Pin GPIO_PIN_4
#define M4_IN1_GPIO_Port GPIOB
#define M4_IN2_Pin GPIO_PIN_5
#define M4_IN2_GPIO_Port GPIOB
#define RC_Throttle_Pin GPIO_PIN_8
#define RC_Throttle_GPIO_Port GPIOB
#define RC_Steering_Pin GPIO_PIN_9
#define RC_Steering_GPIO_Port GPIOB

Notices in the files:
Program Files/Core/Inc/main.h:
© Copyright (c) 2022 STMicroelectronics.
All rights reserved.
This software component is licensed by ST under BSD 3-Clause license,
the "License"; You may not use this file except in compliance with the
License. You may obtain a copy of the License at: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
